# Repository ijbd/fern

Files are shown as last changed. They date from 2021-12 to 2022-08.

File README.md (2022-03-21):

## Introduction
Fern is a bottom-up CNC drawing machine made, with love, in Ann Arbor, Michigan. 
The goal of this project is to make interesting drawn artpieces in collaboration with talented physical artists.

## Table of contents
- [Requirements](#requirements)
- [File Descriptions](#file-descriptions)
- [Example](#examples)
- [Gallery](#gallery)

## Requirements

Hardware:

- Arduino Nano
- NEMA 17 Stepper Motors
- 9g Microservo
- Pololu A4988 Stepper Drivers
- Pololu 16.3mm Snap-Action Switch
- Custom PCB & 3D Printed Joints (in 'parts' folder)

Software:

- Python 3.6
	- pyserial 3.5
	- Pillow 7.2
	- numpy 1.19
- Arduino 1.8.13
	- AccelStepper 1.61.0

## File Descriptions
Coming soon!

## Example
Coming soon!

## Gallery
Coming soon!

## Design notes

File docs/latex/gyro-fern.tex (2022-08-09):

\documentclass{article}
\usepackage{graphicx}
\usepackage{amsmath}
\usepackage{parskip}
\usepackage[margin=1.5in]{geometry}
\title{Supporting Documentation for a Gyroscopic Fern}
\author{ijbd}
\begin{document}

	\section{Introduction}

	The goal of this iteration is to replace the stacked linear axes with a pair of rotating arms (figure \ref{fig:high-level-concept}). 
	This document serves as theoretical foundation and proof-of-concept for this idea.
	
	\begin{figure}[h!]
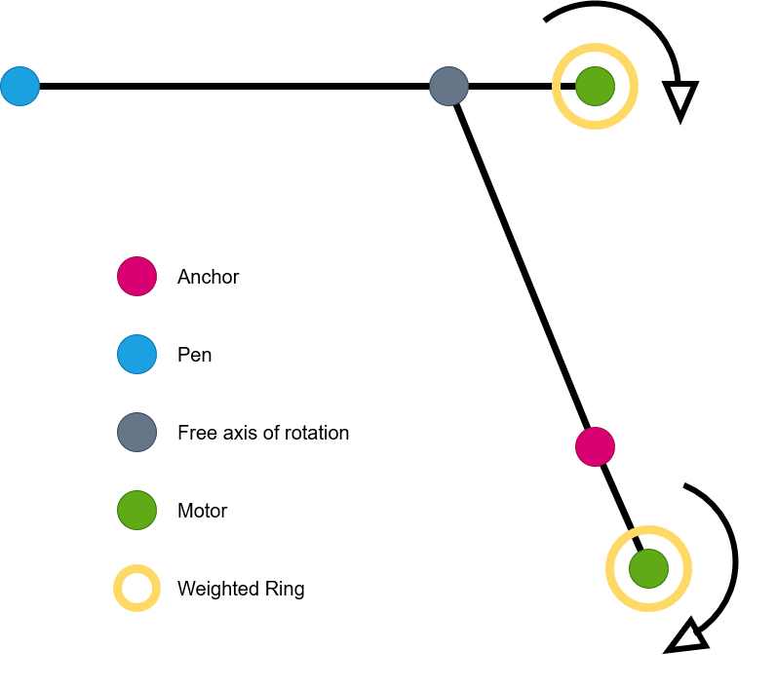
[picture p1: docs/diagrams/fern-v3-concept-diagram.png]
   		   
		\caption{Birds-eye concept drawing of a gyroscopic fern.}
		\label{fig:high-level-concept}
	\end{figure}

	\section{Setup}

	To start, consider a single arm (figure \ref{fig:high-level-one-arm}). It has a motor on one end and an ambiguous mass on the other
	(e.g. a pen or another arm). 

	\begin{figure}[h!]
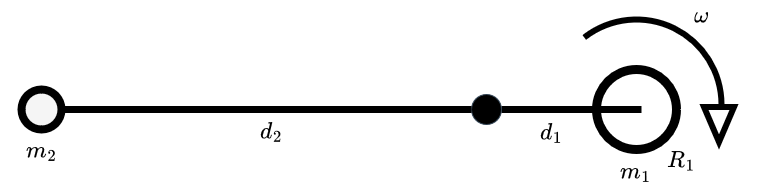
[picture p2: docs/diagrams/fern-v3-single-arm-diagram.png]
		   
	 	\caption{Body diagram for one arm.}
	 	\label{fig:high-level-one-arm}
 	\end{figure}

	Assume the motor and supporting rod are massless.
	With the system at rest, the angular momentum is zero. 
	Suppose the motor begins to spin such that the angular rotation about the rotor axis is $\omega$.
	We want to predict the resulting arm motion.
	The conservation of angular momentum says that the change in angular momentum of a system (lacking an external torques)
	is zero. 
	To express the rotational velocity of the arm as a function of motor speed,
	we can equate the angular momentum of the motor with the angular momentum of the arm.

	\section{Calculation}
	\subsection{Angular Momentum from the Spinning Ring}

	By definition...
	\begin{align}
		L &= \vec{r} \times\vec{p}
	 	&= \vec{r} \times m \vec{v} \\
		&= \int_m\vec{r}\times\vec{v} dm \\
		&= \int_{\theta}\vec{r}\times\rho\vec{v} d\theta
	\end{align}

	Where...
	\begin{align}
		\rho &= \frac{m_1}{2\pi}
	\end{align}

	The components of this integral are shown in figure \ref{fig:one-arm-integral}

	\begin{figure}[h!]
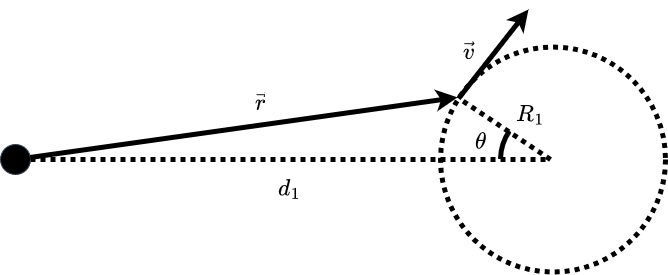
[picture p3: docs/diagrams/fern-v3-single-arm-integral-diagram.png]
		   
	 	\caption{Components of angular momentum integration.}
	 	\label{fig:one-arm-integral}
 	\end{figure}

	Continuing...
	\begin{align}
		L &= \rho\int_0^{2\pi}|\vec{r}(\theta)||\vec{v}|sin(\phi(\theta))d\theta
	\end{align}

	Where..
	\begin{align}
		\phi &= \angle\vec{v} - \angle\vec{r}
	\end{align}

	Solving for the needed quanitities (figure \ref{fig:one-arm-integral-angles})
	\begin{align}
		|\vec{r}(\theta)| &= \sqrt{R_1^2 + d_1^2 -2R_1d_1cos(\theta)} \\
		|\vec{v}| &= \omega r\\
		\phi(\theta) &= \frac{\pi}{2}-\theta-\alpha(\theta)
	\end{align}
	
	Where...
	\begin{align}
		\alpha &= \angle\vec{r}\\
		 &= sin^{-1}(\frac{R_1sin(\theta)}{|\vec{r}(\theta)|})
	\end{align}

	\begin{figure}[h!]
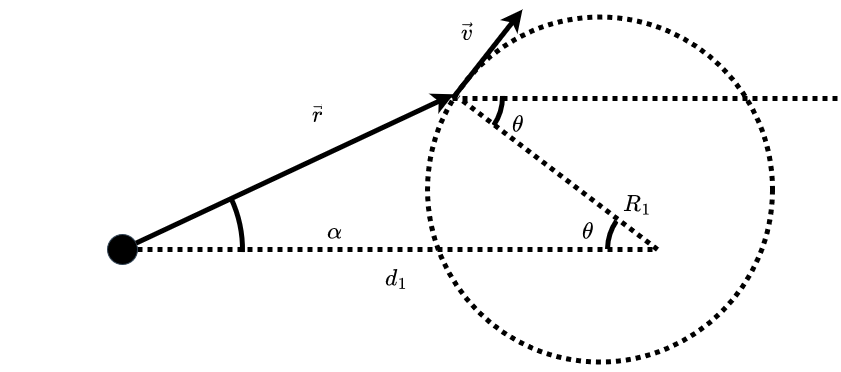
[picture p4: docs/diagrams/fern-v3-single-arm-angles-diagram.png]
		   
	 	\caption{Components of angular momentum integration.}
	 	\label{fig:one-arm-integral-angles}
 	\end{figure}

	Continuing...
	\begin{align}
		sin(\phi(\theta)) &= sin(\frac{\pi}{2}-(\theta+\alpha(\theta)))
	\end{align}

	To simplify...
	\begin{align}
		sin(\phi(\theta)) &= cos(\theta + \alpha(\theta)) \\
		 &= cos(\theta)cos(\alpha(\theta)) - sin(\theta)sin(\alpha(\theta)) \\
		 &= cos(\theta)cos(sin^{-1}(\frac{R_1sin(\theta)}{|\vec{r}(\theta)|})) - sin(\theta)sin(sin^{-1}(\frac{R_1sin(\theta)}{|\vec{r}(\theta)|})) \\
		 &= cos(\theta)\sqrt{1-\frac{R_1^2sin^2(\theta)}{|\vec{r}(\theta)|^2}} - \frac{R_1}{|\vec{r}(\theta)|}sin^2(\theta) \\
		 &= cos(\theta)\sqrt{\frac{|\vec{r}(\theta)|^2 - R_1^2sin^2(\theta)}{|\vec{r}(\theta)|^2}} - \frac{R_1}{|\vec{r}(\theta)|}sin^2(\theta) \\
		 &= cos(\theta)\sqrt{\frac{R_1^2+d_1^2-2R_1d_1cos(\theta)- R_1^2sin^2(\theta)}{|\vec{r}(\theta)|^2}} - \frac{R_1}{|\vec{r}(\theta)|}sin^2(\theta) \\
		 &= cos(\theta)\sqrt{\frac{R_1^2(1-sin^2(\theta))+d_1^2-2R_1d_1cos(\theta)}{|\vec{r}(\theta)|^2}} - \frac{R_1}{|\vec{r}(\theta)|}sin^2(\theta) \\
		 &= cos(\theta)\sqrt{\frac{R_1^2cos^2(\theta)+d_1^2-2R_1d_1cos(\theta)}{|\vec{r}(\theta)|^2}} - \frac{R_1}{|\vec{r}(\theta)|}sin^2(\theta) \\
		 &= cos(\theta)\sqrt{\frac{(R_1cos(\theta) - d_1)^2}{|\vec{r}(\theta)|^2}} - \frac{R_1}{|\vec{r}(\theta)|}sin^2(\theta) \\
		 &= \frac{d_1cos(\theta) - R_1cos^2(\theta) - R_1sin^2(\theta)}{|\vec{r}(\theta)|} \\
		 &= \frac{d_1cos(\theta) - R_1(cos^2(\theta) + sin^2(\theta))}{|\vec{r}(\theta)|} \\
		 &= \frac{d_1cos(\theta) - R_1}{|\vec{r}(\theta)|}
	\end{align}
	Recall...
	\begin{align}
		L &= \rho\int_0^{2\pi}|\vec{r}(\theta)||\vec{v}|sin(\phi(\theta))d\theta
	\end{align}

	Finally...
	\begin{align}
		L &=\rho\omega R_1\int_0^{2\pi}|\vec{r}(\theta)|\frac{d_1cos(\theta) - R_1}{|\vec{r}(\theta)|}d\theta \\
		 &= \rho\omega R_1\int_0^{2\pi}d_1cos(\theta) - R_1 d\theta \\
		 &= \rho\omega R_1^2 2\pi \\
		 &= \frac{m}{2\pi} \omega R_1^2 2\pi  \\
		 &= m \omega R_1^2
	\end{align}
	
\end{document}

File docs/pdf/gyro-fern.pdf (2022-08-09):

## 1 Introduction

The goal of this iteration is to replace the stacked linear axes with a pair of rotating arms (figure 1). This document serves as theoretical foundation and proof-of-concept for this idea.

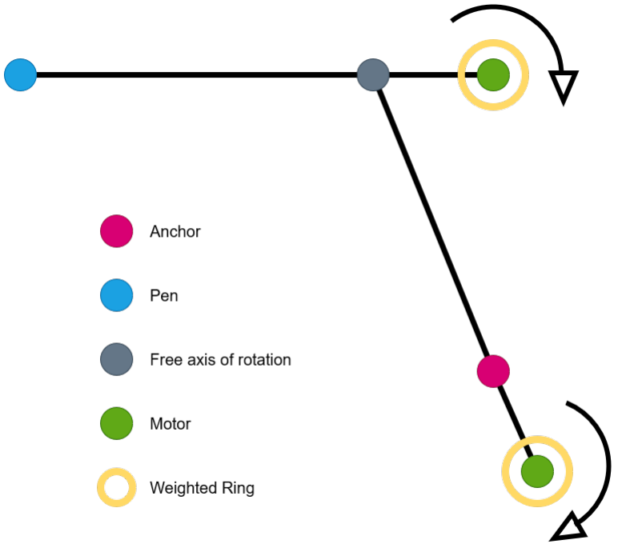
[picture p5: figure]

Figure 1: Birds-eye concept drawing of a gyroscopic fern.

## 2 Setup

To start, consider a single arm (figure 2). It has a motor on one end and an ambiguous mass on the other (e.g. a pen or another arm).

Assume the motor and supporting rod are massless. With the system at rest, the angular momentum is zero. Suppose the motor begins to spin such that the angular rotation about the rotor axis is ω. We want to predict the resulting arm motion. The conservation of angular momentum says that the change in angular momentum of a system (lacking an

1

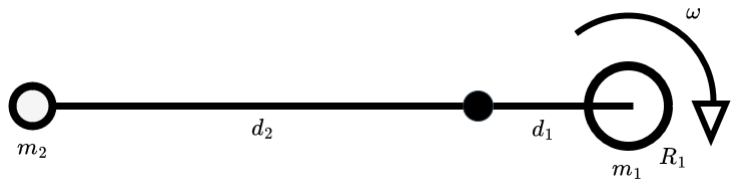
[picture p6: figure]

Figure 2: Body diagram for one arm.

external torques) is zero. To express the rotational velocity of the arm as a function of motor speed, we can equate the angular momentum of the motor with the angular momentum of the arm.

## 3 Calculation

### 3.1 Angular Momentum from the Spinning Ring

By definition...

L = ⃗r × ⃗p | (1)
= ⃗r × m⃗v | (2)

=

Z

m

⃗r × ⃗vdm | (3)

=

Z

θ

⃗r × ρ⃗vdθ | (4)

Where...

ρ =

m1
2π

(5)

The components of this integral are shown in figure 3

Continuing...

L = ρ

Z 2π

0

|⃗r(θ)||⃗v|sin(ϕ(θ))dθ | (6)

Where..

ϕ = ̸ ⃗v − ̸ ⃗r | (7)

2


Figure 3: Components of angular momentum integration.

Solving for the needed quanitities (figure 4)

|⃗r(θ)| =

q
R²
1 + d

2
1 − 2R1d1cos(θ) | (8)
|⃗v| = ωr | (9)
ϕ(θ) = π
2
− θ − α(θ) | (10)

Where...

α = ̸ ⃗r | (11)

= sin⁻¹
(

R1sin(θ)
|⃗r(θ)|
) | (12)

Continuing...

sin(ϕ(θ)) = sin(

π
2
− (θ + α(θ))) | (13)

3

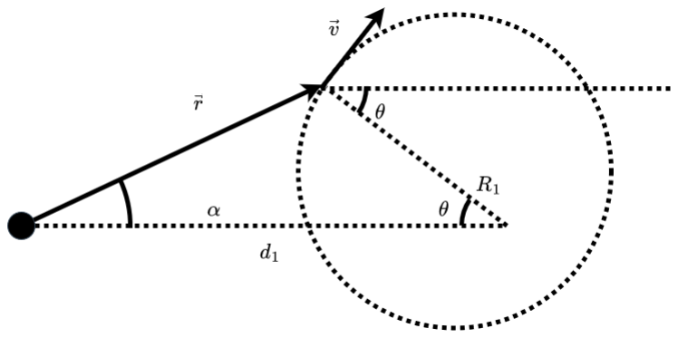
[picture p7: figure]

Figure 4: Components of angular momentum integration.

To simplify...

sin(ϕ(θ)) = cos(θ + α(θ)) | (14)
= cos(θ)cos(α(θ)) − sin(θ)sin(α(θ)) | (15)

= cos(θ)cos(sin⁻¹
(

R1sin(θ)
|⃗r(θ)|

)) − sin(θ)sin(sin⁻¹
(

R1sin(θ)
|⃗r(θ)|

)) (16)

= cos(θ)

s
1 −

R²
1

sin²(θ)
|⃗r(θ)|

2

−

R1
|⃗r(θ)|

sin²
(θ) | (17)

= cos(θ)

s
|⃗r(θ)|

2 − R²
1

sin²(θ)
|⃗r(θ)|

2

−

R1
|⃗r(θ)|

sin²
(θ) | (18)

= cos(θ)

s
R²
1 + d

2

1 − 2R1d1cos(θ) − R²
1

sin²(θ)
|⃗r(θ)|

2

−

R1
|⃗r(θ)|

sin²
(θ) (19)

= cos(θ)

s
R²
1

(1 − sin²(θ)) + d

2
1 − 2R1d1cos(θ)
|⃗r(θ)|

2

−

R1
|⃗r(θ)|

sin²
(θ) (20)

= cos(θ)

s
R²
1

cos²(θ) + d

2
1 − 2R1d1cos(θ)
|⃗r(θ)|

2

−

R1
|⃗r(θ)|

sin²
(θ) | (21)

= cos(θ)

s
(R1cos(θ) − d1)

2
|⃗r(θ)|

2

−

R1
|⃗r(θ)|

sin²
(θ) | (22)

=

d1cos(θ) − R1cos²

(θ) − R1sin²
(θ)
|⃗r(θ)|
| (23)

=

d1cos(θ) − R1(cos²

(θ) + sin²
(θ))
|⃗r(θ)|
| (24)

=

d1cos(θ) − R1
|⃗r(θ)|
| (25)

4

Recall...

L = ρ

Z 2π

0

|⃗r(θ)||⃗v|sin(ϕ(θ))dθ | (26)

Finally...

L = ρωR1

Z 2π

0

|⃗r(θ)|

d1cos(θ) − R1
|⃗r(θ)|
dθ | (27)

= ρωR1

Z 2π

0

d1cos(θ) − R1dθ | (28)

= ρωR²
12π | (29)

=

m
2π

ωR²
12π | (30)

= mωR²
1

(31)

5

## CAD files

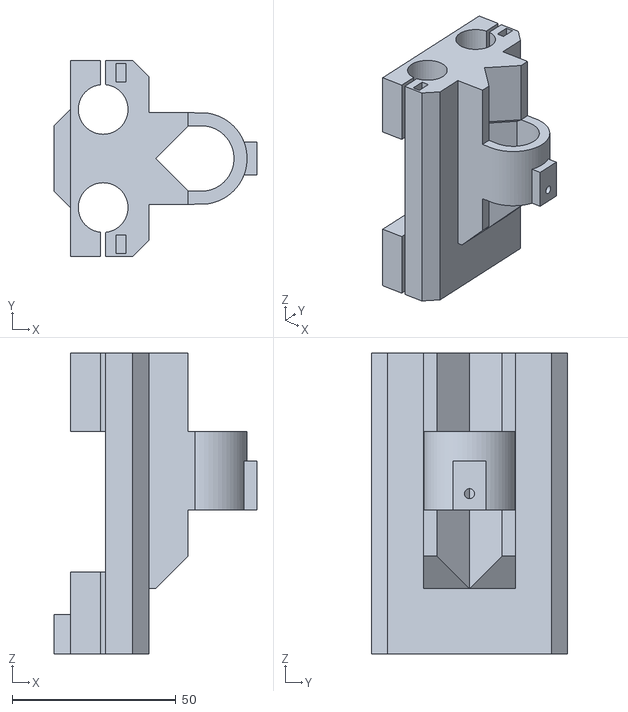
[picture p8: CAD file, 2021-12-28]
parts/pen-holder v9.stl
62.0 x 60.0 x 92.0

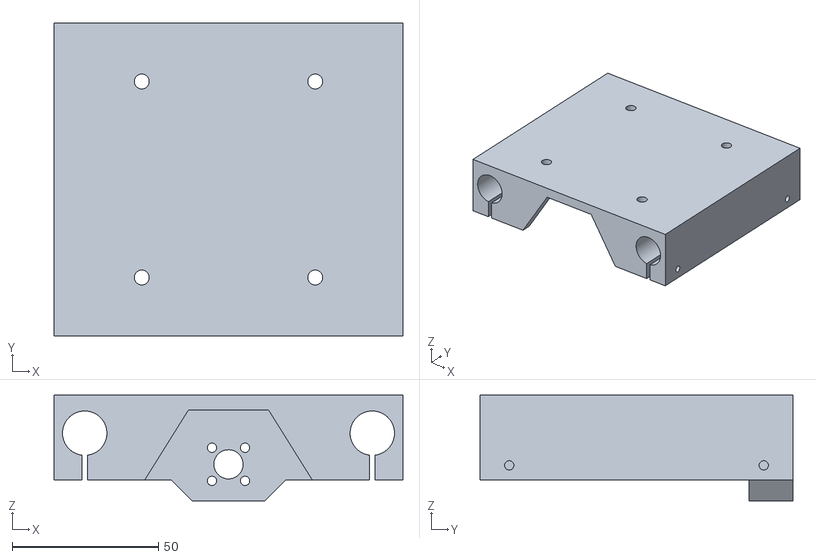
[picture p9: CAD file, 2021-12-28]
parts/y-axis-slider-frame v22.stl
119.3 x 107.0 x 36.1

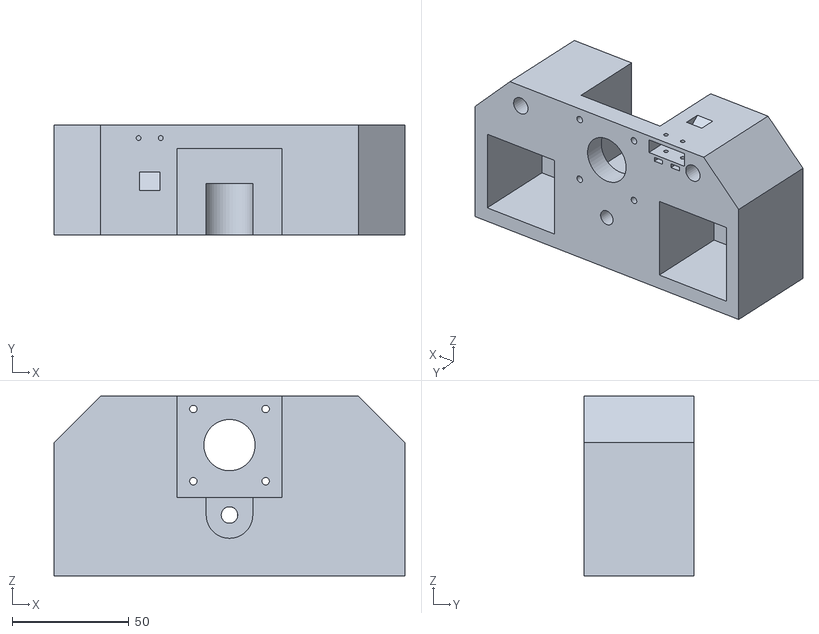
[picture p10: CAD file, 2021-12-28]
parts/y-axis-motor-side-frame v16.stl
150.6 x 47.0 x 77.2

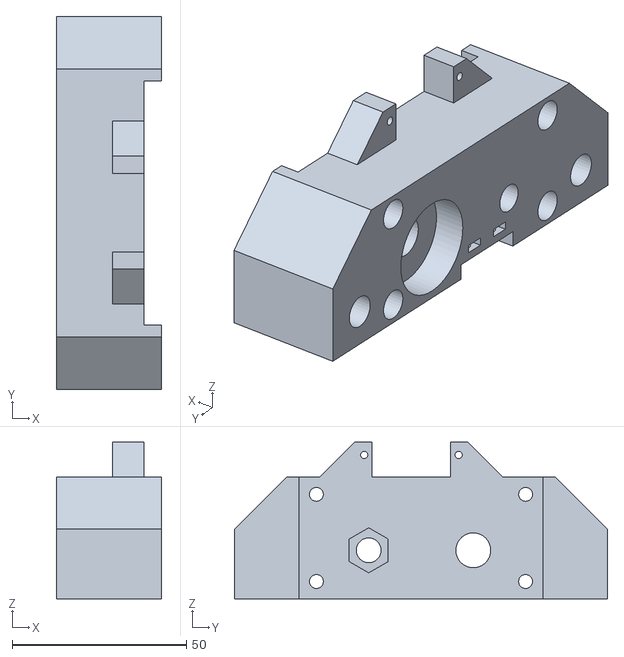
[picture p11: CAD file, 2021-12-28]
parts/x-axis-pen-side-frame v20.stl
30.0 x 107.0 x 45.0

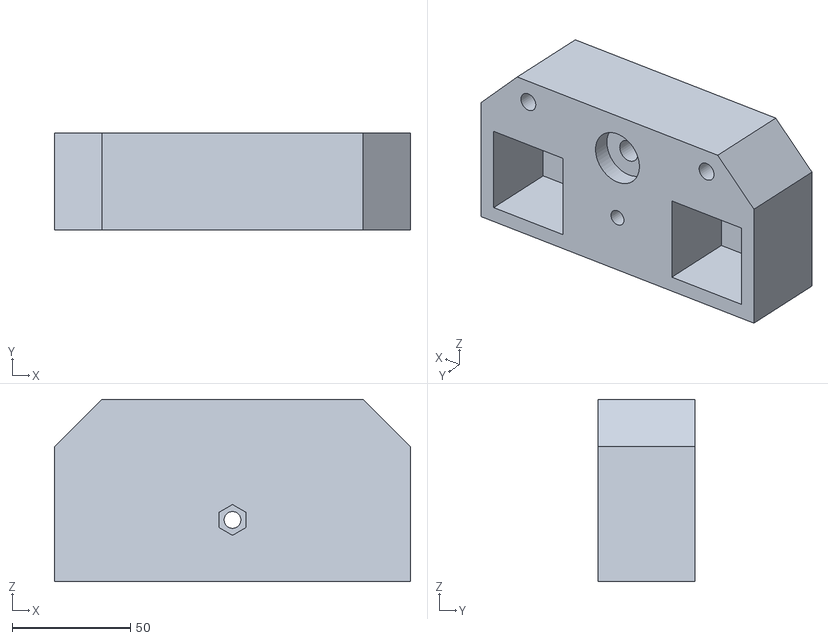
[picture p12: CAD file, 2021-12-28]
parts/y-axis-bearing-side-frame v5.stl
150.6 x 41.0 x 77.2

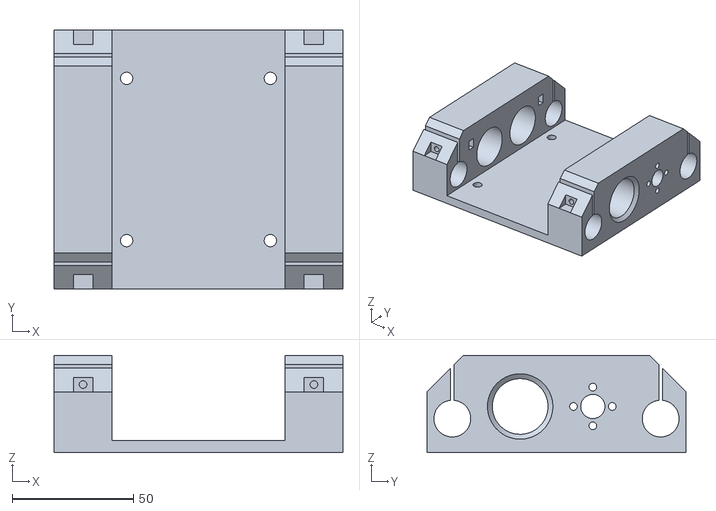
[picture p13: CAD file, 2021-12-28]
parts/x-axis-slider-frame v18.stl
119.3 x 107.0 x 40.0

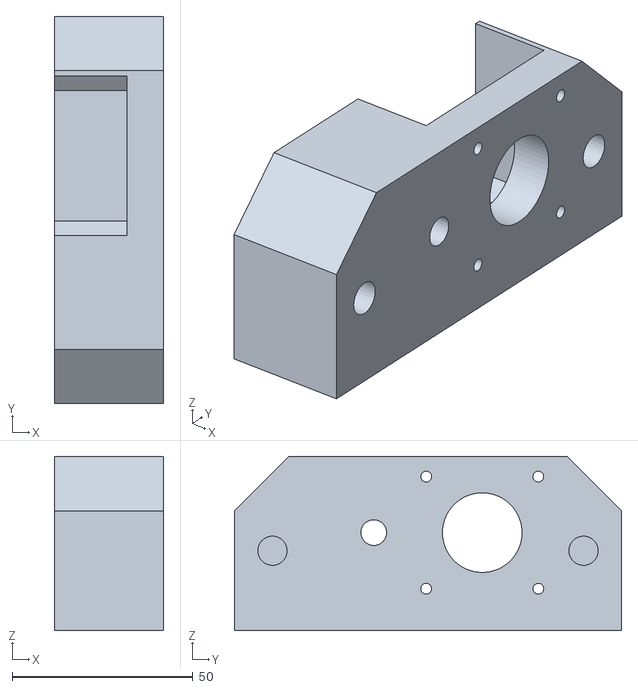
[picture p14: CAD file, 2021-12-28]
parts/x-axis-motor-side-frame v19.stl
30.0 x 107.0 x 48.1

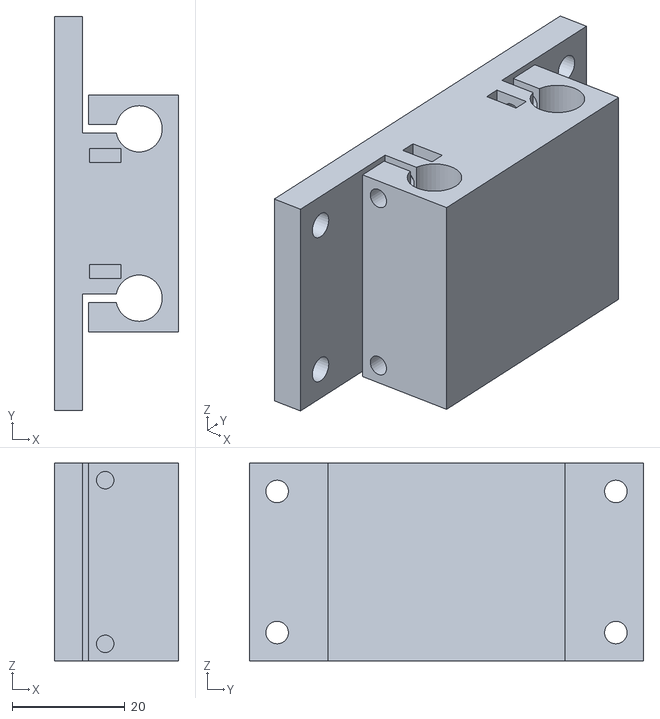
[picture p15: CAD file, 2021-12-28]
parts/pen-rail-frame v17.stl
22.0 x 69.8 x 35.0

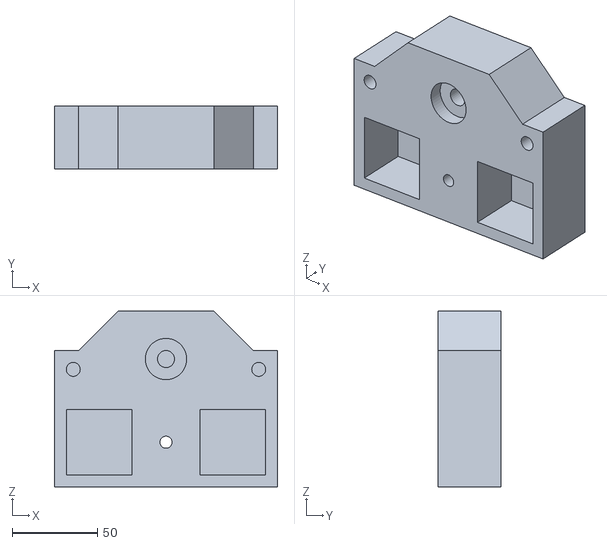
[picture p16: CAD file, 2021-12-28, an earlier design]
parts/y-axis-bearing-side-frame v3.stl
130.6 x 37.0 x 102.9

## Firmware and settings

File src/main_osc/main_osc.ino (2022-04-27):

/* Fern
 * ~~~~~~~~~~~
 * Code by ijbd
 */

// includes
#include <Servo.h>
#include <AccelStepper.h>
#include <MultiStepper.h>

// defines
#define MOTOR_A_DIR_PIN 2
#define MOTOR_A_STEP_PIN 3
#define MOTOR_A_MS_1_PIN 5
#define MOTOR_A_MS_2_PIN 4
#define MOTOR_A_INVERT false
#define MOTOR_B_DIR_PIN 6
#define MOTOR_B_STEP_PIN 7
#define MOTOR_B_MS_1_PIN 9
#define MOTOR_B_MS_2_PIN 8
#define MOTOR_B_INVERT false
#define SERVO_PIN 10
#define SERVO_ANGLE_DOWN 0
#define SERVO_ANGLE_UP 60
#define SERVO_DELAY_MS 250
#define BUMPER_X_PIN 11
#define BUMPER_Y_PIN 12
#define STEP_MAX_SPEED 400
#define STEPS_PER_MM 25 
#define X_LIM_STEPS 6250
#define Y_LIM_STEPS 7500

// oscillate
#define SP_PIN A1
#define NF_PIN A2
#define DF_PIN A4
#define OSC_TS .01

// struct
class Fern{
public:
  Fern():pen(),motor_a(),motor_b(),motors(),pen_state(0){
    // attach servo
    pen.attach(SERVO_PIN);

    // init motors
    init_motors();

    // go home
    go_home();
  }

  void init_motors(){
    
    // instantiate motors
    motor_a = AccelStepper(AccelStepper::DRIVER,MOTOR_A_STEP_PIN, MOTOR_A_DIR_PIN);
    motor_b = AccelStepper(AccelStepper::DRIVER,MOTOR_B_STEP_PIN, MOTOR_B_DIR_PIN);
  
    // set microstep pins
    digitalWrite(MOTOR_A_MS_1_PIN, LOW);
    digitalWrite(MOTOR_A_MS_2_PIN, HIGH);
    digitalWrite(MOTOR_B_MS_1_PIN, LOW);
    digitalWrite(MOTOR_B_MS_2_PIN, HIGH);
  
    // limit speed
    motor_a.setMaxSpeed(STEP_MAX_SPEED);
    motor_b.setMaxSpeed(STEP_MAX_SPEED);
  
    // invert pins if necessery
    motor_a.setPinsInverted(MOTOR_A_INVERT);
    motor_b.setPinsInverted(MOTOR_B_INVERT);
  
    // add motor
    motors.addStepper(motor_a);
    motors.addStepper(motor_b);
  }

  void go_home(){
    
    // lift 
    raise_pen();
    
    // find x = 0
    while(digitalRead(BUMPER_X_PIN)){
      motor_a.setSpeed(-STEP_MAX_SPEED);
      motor_a.runSpeed();   
      motor_b.setSpeed(-STEP_MAX_SPEED);
      motor_b.runSpeed();   
    }
    
    // find y = 0
    while(digitalRead(BUMPER_Y_PIN)){
      motor_a.setSpeed(STEP_MAX_SPEED);
      motor_a.runSpeed();
      motor_b.setSpeed(-STEP_MAX_SPEED);
      motor_b.runSpeed();
    }
   
    // set position
    motor_a.setCurrentPosition(0);
    motor_b.setCurrentPosition(0);
  }

  void move_to(int x, int y){
    
    // rotate x/y into a/b coordinate system
    long dest[2];
    
    dest[0] = .707*(x-y);
    dest[1] = .707*(x+y);

    motors.moveTo(dest);
    motors.runSpeedToPosition();
  }

  void raise_pen(){
    if(!pen_state){
      pen.write(SERVO_ANGLE_UP);
      pen_state = HIGH;
      delay(SERVO_DELAY_MS);
    }
  }

  void lower_pen(){
    if(pen_state){
      pen.write(SERVO_ANGLE_DOWN);
      pen_state = LOW;
      delay (SERVO_DELAY_MS);
    }
  }

  void parse_serial(){

    // send ready
    Serial.write('R');
    
    // wait for incoming instruction
    while(!Serial.available());

    // load fields
    char opcode;
    char field1[6];
    char field2[6];
    
    opcode = Serial.read();
    Serial.readBytes(field1,6);
    Serial.readBytes(field2,6);

    // execute
    switch(opcode){
      case 'M':
        parse_move(field1, field2);
        break;
      case 'P':
        parse_pen(field1);
        break;
    }
  }

  void parse_move(char * field1, char * field2){

    // read arguments
    float x_mm_dest = atof(field1);
    float y_mm_dest = atof(field2);

    // convert to steps
    int x_dest = x_mm_dest * STEPS_PER_MM;
    int y_dest = y_mm_dest * STEPS_PER_MM;

    // limit check
    x_dest = min(X_LIM_STEPS, max(x_dest, 0));
    y_dest = min(Y_LIM_STEPS, max(y_dest, 0));

    // move 
    move_to(x_dest,y_dest);
  }

  void parse_pen(char * field1){

    // read argument
    int pen_state_dest = field1[1] - '0';

    if(pen_state_dest){
      raise_pen();
    }
    else{
      lower_pen();
    }
  }
  
private:
  Servo pen;
  AccelStepper motor_a;
  AccelStepper motor_b;
  MultiStepper motors;
  int pen_state;
};


float get_set_point(){
  return 0.5*(1023-analogRead(SP_PIN)) / 1024;
}

float get_nat_freq(){
  return 5.0*(1024-analogRead(NF_PIN)) / 1024;
}

float get_damp_factor(){
  return max(.1, 1.0*(1024-analogRead(DF_PIN)) / 1024);
}


void pin_setup(){
  pinMode(MOTOR_A_STEP_PIN, OUTPUT);
  pinMode(MOTOR_A_DIR_PIN, OUTPUT);
  pinMode(MOTOR_A_MS_1_PIN, OUTPUT);
  pinMode(MOTOR_A_MS_2_PIN, OUTPUT);

  pinMode(MOTOR_B_STEP_PIN, OUTPUT);
  pinMode(MOTOR_B_DIR_PIN, OUTPUT);
  pinMode(MOTOR_B_MS_1_PIN, OUTPUT);
  pinMode(MOTOR_B_MS_2_PIN, OUTPUT);

  pinMode(SERVO_PIN, OUTPUT);

  // oscillator
  pinMode(SP_PIN, INPUT);
  pinMode(NF_PIN, INPUT);
  pinMode(DF_PIN, INPUT);
}

void setup(){
  Serial.begin(115200);

  pin_setup();

  Fern fern;

  delay(5000);

  // params

  float xc = 90;
  float yc = 80;
  float scale = 80;
  
  // initial conditions
  float theta = 3.14*random(0,10)/10;
  float r = get_set_point();
  float dr = 0;
  float dr2;

  float x = xc + r*scale*cos(theta);
  float y = yc + r*scale*sin(theta);

  int x_dest = min(X_LIM_STEPS, max(x*STEPS_PER_MM, 0));
  int y_dest = min(Y_LIM_STEPS, max(y*STEPS_PER_MM, 0));
  
  fern.move_to(x_dest, y_dest);
  fern.lower_pen();
  
  while(1){
    float u = get_set_point();
    float w_n = get_nat_freq();
    float zeta = get_damp_factor();

    r += .5*dr*OSC_TS;
    dr2 = w_n*w_n*(u-r)-2*w_n*zeta*dr;
    r += .5*dr*OSC_TS;
    dr += dr2*OSC_TS;

    theta = fmod(theta + OSC_TS/20, 2*3.14159);

    x = xc + r*scale*cos(theta);
    y = yc + r*scale*sin(theta);

    // limit check
    int x_dest = min(X_LIM_STEPS, max(x*STEPS_PER_MM, 0));
    int y_dest = min(Y_LIM_STEPS, max(y*STEPS_PER_MM, 0));

    // move 
    fern.move_to(x_dest,y_dest);
  }
}

void loop() {
  
}

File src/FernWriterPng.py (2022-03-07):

import serial
import sys
import argparse
import cairo
import os

from FernWriter import FernWriter

PEN_WIDTH = .5
FERN_WIDTH = 250
FERN_HEIGHT = 300
PNG_SCALE = 3

class FernWriterPng(FernWriter):
	
	def send_move_instr(self, x_dest, y_dest):
		if not self.pen_state:
			self.context.move_to(self.x_state/FERN_WIDTH,self.y_state/FERN_HEIGHT)
			self.context.line_to(x_dest/FERN_WIDTH, y_dest/FERN_HEIGHT)
			self.context.stroke()

		self.x_state = x_dest
		self.y_state = y_dest

		return None
	
	def send_pen_instr(self,new_pen_state):
		self.pen_state = new_pen_state != 0
		return None
   
def main(instruction_file, png_file):

	# setup
	surface = cairo.SVGSurface("tmp.svg",FERN_WIDTH*PNG_SCALE,FERN_HEIGHT*PNG_SCALE)

	# setup context
	context = cairo.Context(surface)
	context.set_source_rgb(1,1,1)
	context.scale(FERN_WIDTH*PNG_SCALE,FERN_HEIGHT*PNG_SCALE)
	context.rectangle(0,0,1,1)
	context.fill()
	context.set_line_width(PEN_WIDTH/FERN_WIDTH)
	context.set_line_cap(cairo.LINE_CAP_ROUND)
	context.set_source_rgb(0,0,0)

	# call writer
	f = FernWriterPng(context)
	f.draw(instruction_file)

	# save
	surface.write_to_png(png_file)

	return None

if __name__ == '__main__':

	parser = argparse.ArgumentParser()

	parser.add_argument('instruction_file',type=str)
	parser.add_argument('png_file',type=str)

	args = parser.parse_args()

	main(args.instruction_file, args.png_file)

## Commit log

2021-12-16 lib control. unstable circle.
    [main.ino]
2021-12-28 Add parts.
    [pen-holder v9.stl, pen-rail-frame v17.stl, x-axis-motor-side-frame v19.stl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]
2022-01-14 City scape script! Prior to redesign.
    [FernArtist.py, main.ino]
2022-07-15 Unit testing framework.
2022-08-06 Add server folder.
    [fern-mcu.kicad_pcb, fern-mcu.kicad_sch]
2022-08-07 Added fern-v3-single-arm-diagram.drawio
2022-08-07 Added fern-v3-single-arm-integral-diagram.drawio
2022-08-07 Added fern-v3-single-arm-angles-diagram.drawio
2022-08-09 Switch latex action.
2022-08-09 Added fern-v3-single-arm-angles-diagram.drawio.png
2022-08-09 Added fern-v3-single-arm-diagram.drawio.png
2022-08-09 Added fern-v3-single-arm-integral-diagram.drawio.png
